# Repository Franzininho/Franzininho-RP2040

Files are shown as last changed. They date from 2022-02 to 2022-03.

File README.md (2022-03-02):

# Franzininho-RP2040

Placa para teste do RP2040

## Brainstorming

### Recursos:
- Display IPS com st7735 [1.3 TFT](https://pt.aliexpress.com/item/4001282467099.html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)
- Formato conoforme esse guia (https://github.com/microsoft/pxt-arcade-hardware-designs/pulls)
- Conector para micro sd card [exemplo](https://pt.aliexpress.com/item/1005002327556213.html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)
- Bateria - Circuito para gerenciamento de carga
- Pinout para hc-05 (UART)
- USB: Micro
- USB HOST usando PIO 
    https://youtu.be/2eB8p8vo7lw
    https://github.com/pa-art/test_usb_host
    https://github.com/sekigon-gonnoc/qmk_firmware/tree/rp2040/keyboards/pico_pico_usb
- Saída de áudio
- Saída video 
- Expansões: i²c, spi   
 - OPÇÃO:
    - Fazer teclado como placa de expansão
    - Comunicação infrared: https://youtu.be/LPeMlFf0Qso  https://youtu.be/GHWm4mRImoI
    - Motor vibracall
 
### Referências

RP2040:
- https://arcade.makecode.com/hardware/adding
- https://github.com/microsoft/pxt-arcade-hardware-designs/tree/master/ArcadeMVD-STM%20v1.5
- https://news.mkme.org/?p=21518
- https://github.com/microsoft/pxt-arcade-hardware-designs/tree/master/microbit-shield
- https://datasheets.raspberrypi.com/pico/pico-datasheet.pdf
- https://www.sparkfun.com/rp2040#resources
- https://www.youtube.com/watch?v=2eB8p8vo7lw
- https://github.com/pa-art/test_usb_host
- https://github.com/sekigon-gonnoc/qmk_firmware/tree/rp2040/keyboards/pico_pico_usb
- https://learn.adafruit.com/adafruit-pygamer/which-board
- https://www.cnx-software.com/2021/12/31/mico-a-usb-microphone-based-on-raspberry-pi-rp2040-mcu/

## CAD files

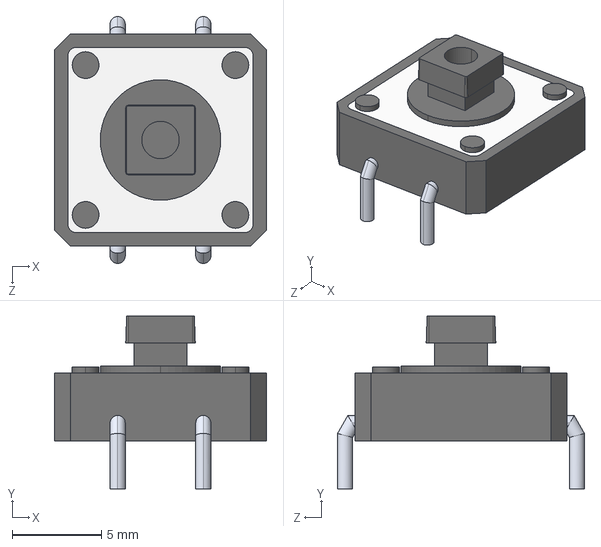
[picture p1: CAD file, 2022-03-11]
Modelos 3D/User_Library-Button_12x12x7_3.step
11.9 x 9.70 x 13.9 mm

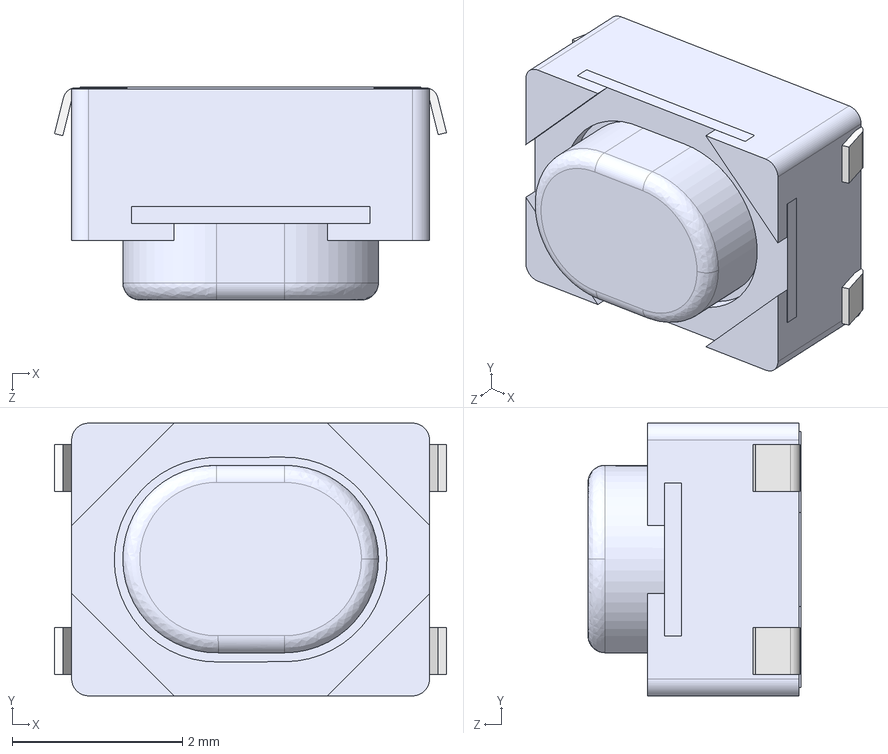
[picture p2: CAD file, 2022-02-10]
Modelos 3D/PTS810.STEP
4.60 x 3.20 x 2.50 mm
Strip
Button
Sheet Metal Part6 x 2
Pin

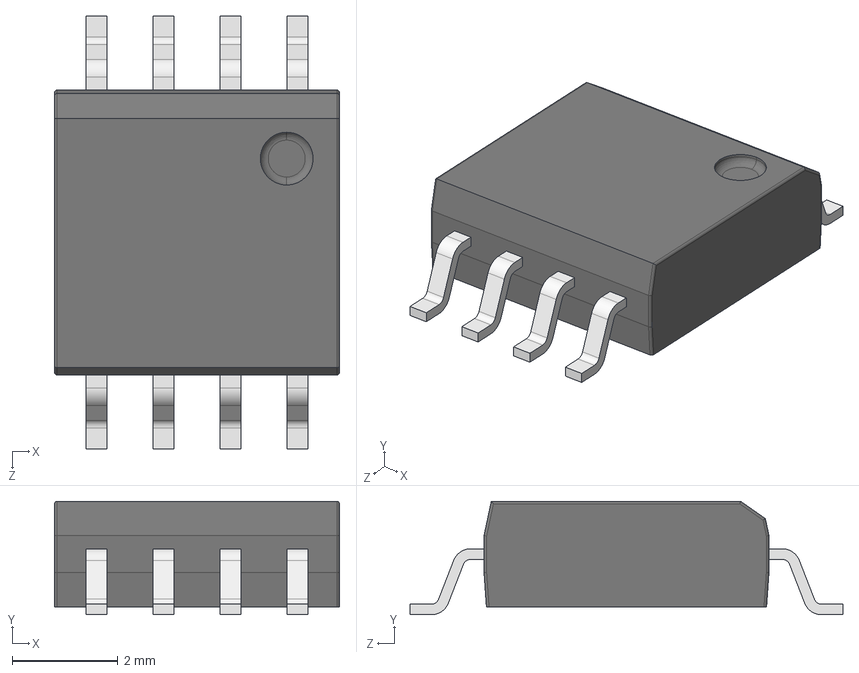
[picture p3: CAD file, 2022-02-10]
Modelos 3D/SOIC-8-208.STEP
5.40 x 2.15 x 8.20 mm
pin_SOIC_SOIC-208_1 x 8
SOIC_150_SOIC_5.4x5.4_1

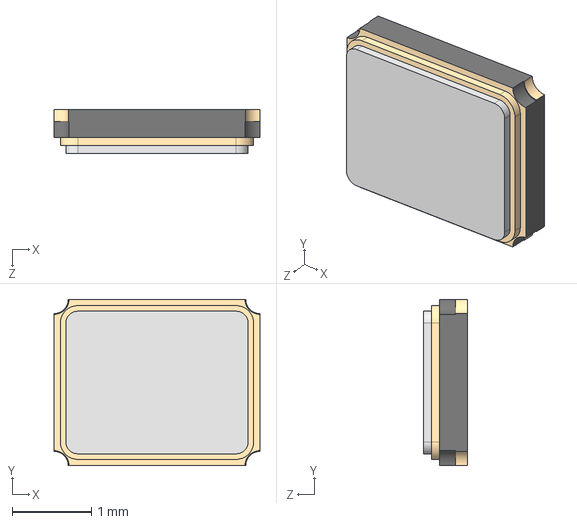
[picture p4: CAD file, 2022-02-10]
Modelos 3D/SMD-2520-4PIN.STEP
2.60 x 2.10 x 0.55 mm

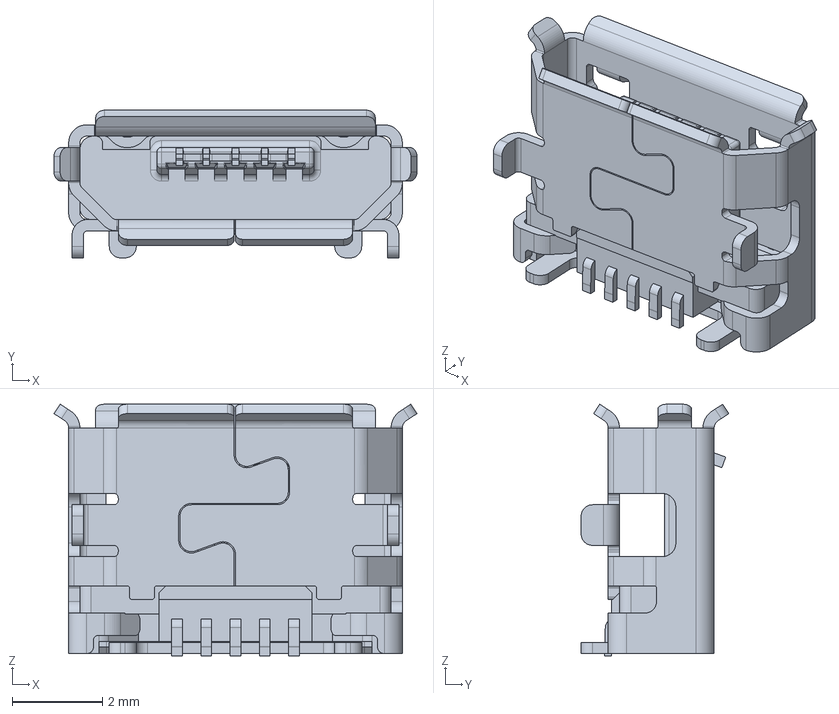
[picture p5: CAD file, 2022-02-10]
Modelos 3D/10118194-0001lf.stp
8.05 x 3.27 x 5.58 mm

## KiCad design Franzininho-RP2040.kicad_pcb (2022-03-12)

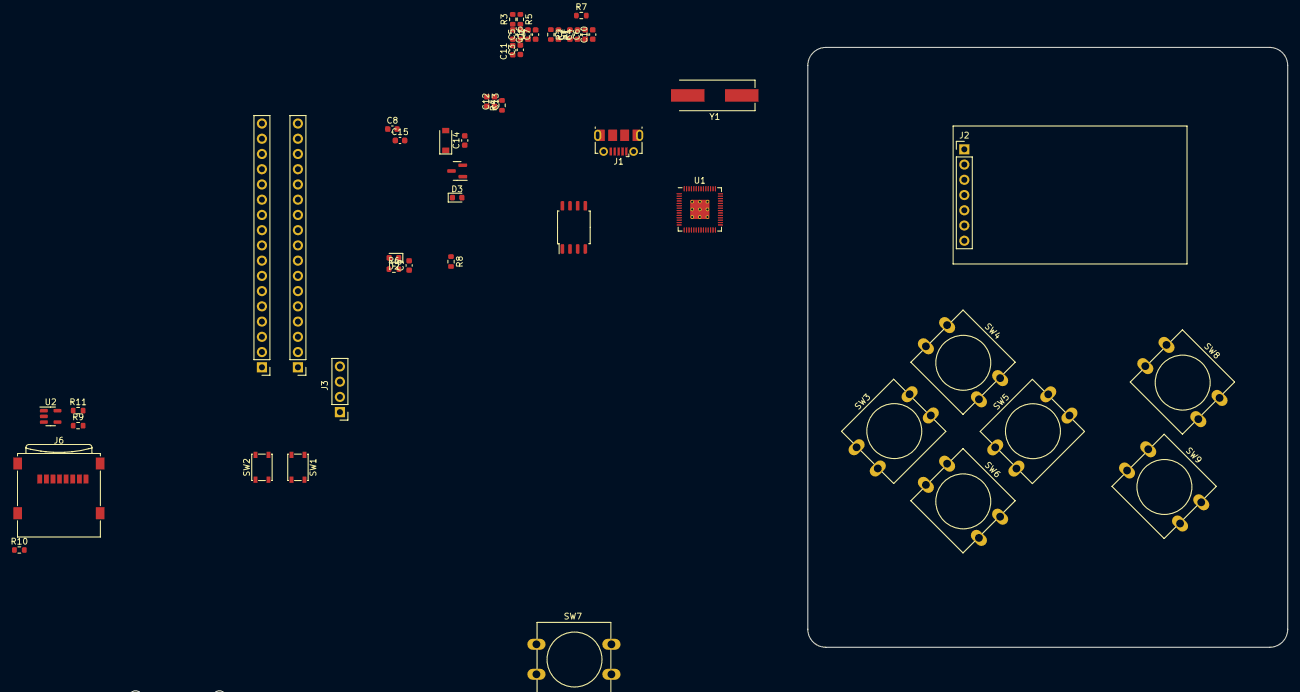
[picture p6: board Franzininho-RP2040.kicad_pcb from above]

Board: 2 copper layers, 80.0 x 100.0 mm, 54 parts (0 on the bottom side), 55 nets, no tracks yet.

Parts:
C1, C3: 1u; C_0603_1608Metric
C2, C4, C5, C6, C7, C8, C9, C10, C11, C16: 100n; C_0603_1608Metric
C12, C13: 27p; C_0603_1608Metric
C14, C15: 10u; C_0603_1608Metric
D1: 1N5819W; D_SOD-123
D2, D3: LED; LED_0603_1608Metric
H1, H2, H3, H4: MountingHole; MountingHole_2.2mm_M2
J1: USB_B_Micro; USB_Micro-B_Molex-105017-0001
J2: Conn_01x07_Male; PinHeader_1x07_P2.54mm_Vertical
J3: Conn_01x04; PinHeader_1x04_P2.54mm_Vertical
J4, J5: Conn_01x17; PinHeader_1x17_P2.54mm_Vertical
J6: Micro_SD_Card; microSD_HC_Wuerth_693072010801
R1, R2: 27; R_0603_1608Metric
R3, R4: 1k; R_0603_1608Metric
R5, R6, R7, R8, R10: 10k; R_0603_1608Metric
R9: 100k; R_0603_1608Metric
R11: DNF; R_0603_1608Metric
SW1, SW2: SW_Push; SW_SPST_PTS810
SW3, SW4, SW5, SW6, SW7, SW8, SW9: SW_Push; SW_PUSH-12mm
U1: RP2040; RP2040-QFN-56
U2: XC6206P332MR; SOT-23
U2#2: AP2112K-3.3; SOT-23-5
U3: W25Q128JVS; SOIC-8_5.23x5.23mm_P1.27mm
Y1: 12MHz; Crystal_SMD_HC49-US

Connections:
+1V1: C3.1, C5.1, C7.1, U1.23 (DVDD), U1.45 (VREG_VOUT), U1.50 (DVDD1)
+3V3: C1.1, C2.1, C4.1, C6.1, C8.1, C9.1, C10.1, C11.1, C15.1, C16.1, J3.1, J4.1, J6.4 (VDD), R5.2, R6.2, R8.2, R10.1, U1.1 (IOVDD), U1.10 (IOVDD1), U1.22 (IOVDD2), U1.33 (IOVDD3), U1.42 (IOVDD4), U1.43 (ADC_AVDD), U1.44 (VREG_VIN), U1.48 (USB_VDD), U1.49 (IOVDD5), U2.2 (VO), U2#2.5 (VOUT), U3.8 (VCC)
+5V: D1.1 (K), J5.1, R9.1, U2.3 (VI), U2#2.1 (VIN)
/BT_A: SW5.1, U1.16 (GPIO13)
/BT_B: SW4.1, U1.17 (GPIO14)
/BT_DOWN: SW6.1, U1.15 (GPIO12)
/BT_LEFT: SW9.1, U1.12 (GPIO9)
/BT_MENU: SW3.1, U1.18 (GPIO15)
/BT_RIGHT: SW8.1, U1.13 (GPIO10)
/BT_UP: SW7.1, U1.14 (GPIO11)
/DISPLAY_DC: J2.6, U1.6 (GPIO4)
/DISPLAY_RES: J2.5, U1.7 (GPIO5)
/DISPLAY_SCL: J2.3, U1.4 (GPIO2)
/DISPLAY_SDA: J2.4, U1.5 (GPIO3)
/GPIO0: J4.17, U1.2 (GPIO0)
/GPIO6: J4.11, U1.8 (GPIO6)
/GPIO7: J4.10, U1.9 (GPIO7)
/GPIO8: J4.9, U1.11 (GPIO8)
/GPIO16: J5.5, U1.27 (GPIO16)
/GPIO17: J5.6, U1.28 (GPIO17)
/GPIO19: J5.8, U1.30 (GPIO19)
/GPIO23: J5.12, U1.35 (GPIO23)
/GPIO24: J5.13, U1.36 (GPIO24)
/GPIO25: R7.2, U1.37 (GPIO25)
/GPIO26_ADC0: J5.14, U1.38 (GPIO26/ADC0)
/GPIO27_ADC1: J5.15, U1.39 (GPIO27/ADC1)
/GPIO28_ADC2: J5.16, U1.40 (GPIO28/ADC2)
/GPIO29_ADC3: J5.17, U1.41 (GPIO29/ADC3)
/POWER_LED: D2.2 (A), R6.1
/QSPI_CLK: U1.52 (QSPI_SCLK), U3.6 (CLK)
/QSPI_SD0: U1.53 (QSPI_SD0), U3.5 (DI(IO0))
/QSPI_SD1: U1.55 (QSPI_SD1), U3.2 (DO(IO1))
/QSPI_SD2: U1.54 (QSPI_SD2), U3.3 (IO2)
/QSPI_SD3: U1.51 (QSPI_SD3), U3.7 (IO3)
/QSPI_SS: R3.1, R5.1, U1.56 (QSPI_SS_N), U3.1 (~CS)
/SD_CLK: J6.5 (CLK), R11.1, U1.3 (GPIO1)
/SD_CMD: J6.3 (CMD), U1.29 (GPIO18)
/SD_DAT1: J6.8 (DAT1), U1.31 (GPIO20)
/SD_DAT2: J6.1 (DAT2), R10.2, U1.32 (GPIO21)
/SD_DAT3: J6.2 (DAT3/CD), U1.34 (GPIO22)
/SWCLK: J3.2, U1.24 (SWCLK)
/SWDIO: J3.3, U1.25 (SWDIO)
/USB_D+: J1.3 (D+), R2.1
/USB_D-: J1.2 (D-), R1.1
/USER_LED: D3.2 (A), R7.1
/XIN: C12.1, U1.20 (XIN), Y1.1
/XOUT: R4.1, U1.21 (XOUT)
/XOUT_R: C13.1, R4.2, Y1.2
/~RESET: R8.1, SW2.2, U1.26 (RUN)
/~USB_BOOT: R3.2, SW1.2
GND: C1.2, C2.2, C3.2, C4.2, C5.2, C6.2, C7.2, C8.2, C9.2, C10.2, C11.2, C12.2, C13.2, C14.2, C15.2, C16.2, D2.1 (K), D3.1 (K), J1.5 (GND), J1.6 (Shield), J2.1, J3.4, J4.2, J5.2, J5.3, J6.6 (VSS), J6.9 (SHIELD), R11.2, SW1.1, SW2.1, SW3.2, SW4.2, SW5.2, SW6.2, SW7.2, SW8.2, SW9.2, U1.19 (TESTEN), U1.57 (PAD), U2.1 (GND), U2#2.2 (GND), U3.4 (GND)
unnamed: R1.2, U1.46 (USB_DM)
unnamed: R2.2, U1.47 (USB_DP)
unnamed: R9.2, U2#2.3 (EN)
VBUS: C14.1, D1.2 (A), J1.1 (VBUS)

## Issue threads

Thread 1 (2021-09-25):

Tornar repositório não vazio

ggrs, 2021-09-25:
Adicionar um README.md ou algum arquivo para que este repositório possa ser forkado/receber PRs.
Fiz um circuito de base e gostaria de já fazer um PR aqui.

FBSeletronica, 2021-09-25:
Adicionado. Obrigado @ggrs

Closed 2021-09-25.

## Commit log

2021-09-25 Circuito base inicial
    [Franzininho-RP2040.kicad_pcb, Franzininho-RP2040.sch, RP2040.step]
2021-11-27 Adição de conector SWD, definição de pinos e pequenas correções
    [Franzininho-RP2040.sch]
2021-12-19 Anotação de esquemático
    [Franzininho-RP2040.sch]
2021-12-19 ERC e correções
    [Franzininho-RP2040.sch]
2021-12-22 Adição de nomes de nets + pequenas melhorias e correções
    [Franzininho-RP2040.sch]
2021-12-22 Geração de netlist e posicionamento inicial de componentes na PCB
2021-12-29 Adição de modelos 3D e melhorias
    [10118194-0001lf.stp, Franzininho-RP2040.kicad_pcb, Franzininho-RP2040.sch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]
2022-01-30 Atualização para KiCad 6
    [Franzininho-RP2040.kicad_pcb, Franzininho-RP2040.kicad_sch]
2022-01-30 Adição de título
    [Franzininho-RP2040.kicad_sch]
2022-02-03 Pequena melhoria nos textos do esquemático
    [Franzininho-RP2040.kicad_sch]
2022-02-04 Incluindo brainstoming para recursos
2022-02-04 Ajuste de bullet points
2022-02-04 Mais opções de recursos
2022-02-10 Aumentar layout da página de esquemático
    [Franzininho-RP2040.kicad_sch]
2022-03-01 Adição de display, botões e cartão SD
    [Franzininho-RP2040.kicad_sch]
2022-03-11 Atualização da PCB
    [Franzininho-RP2040.kicad_pcb, Franzininho-RP2040.kicad_sch, User_Library-Button_12x12x7_3.step]
2022-03-12 Ajuste do outline da placa
    [Franzininho-RP2040.kicad_pcb]
